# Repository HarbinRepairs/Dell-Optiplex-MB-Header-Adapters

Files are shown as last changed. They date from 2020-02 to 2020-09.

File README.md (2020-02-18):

# Front Panel Header Adapters for Dell Optiplex Motherboards

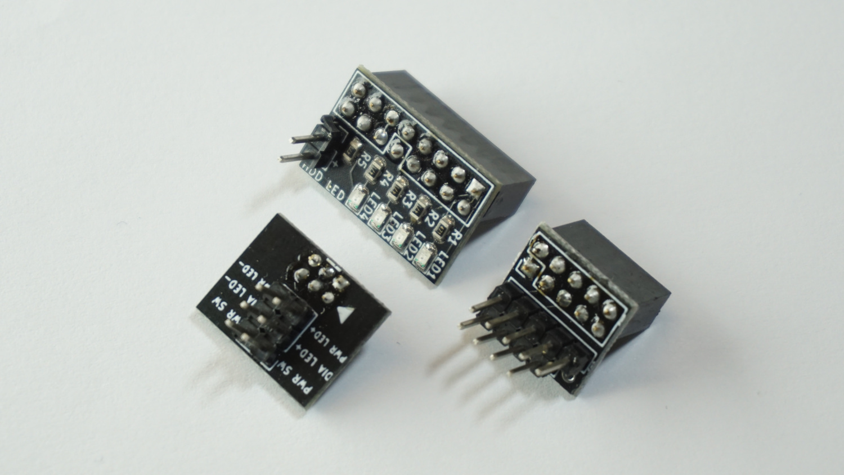
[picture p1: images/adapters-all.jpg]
Adapters


Get it at our store:

https://store.harbinrepairs.com/index.php/product/dell-optiplex-390-3010-3020-front-panel-header-adapter-3pc-kit/

https://store.harbinrepairs.com/index.php/product/dell-5-6-pin-power-button-led-panel-adapter/

Get it on eBay:

https://www.ebay.com/itm/264638815586

https://www.ebay.com/itm/264638806788

## License
Harbin Repairs 2020
Creative Commons Attribution ShareAlike 4.0
https://creativecommons.org/licenses/by-sa/4.0/

GNU General Public License v3.0

Harbin Repairs is not affiliated with Dell in any way shape or form.

## Documentation

This kit is designed for the mid tower (not SFF or small form factor) desktops. It allows you to connect standard PC case front panel headers to the Dell Optiplex 390, 3010, and 3020 motherboards. These are often used to build budget gaming PC’s using decommissioned office desktops and convert them to work with modern PC cases. WARNING! Connecting these adapters in the wrong orientation or with the wrong models could result in damage to your motherboard. Do not use these adapters with models other than the ones mentioned above and make sure to check out our assembly video below.

### Installation Guide Video

https://www.youtube.com/watch?v=3fb6-B5Ux_s

(https://www.youtube.com/watch?v=3fb6-B5Ux_s)

### Compatibility

The three piece adapter kit is only compatibile with the Dell optiplex 390, 3010, and 3020 DT & MT Dekstops. It will not work on the SFF desktops since they use a different connector and are not ideal since they do not have a removable I/O shield. The 5/6 pin power button however may work with most dell desktops that have a 5/6 pin header for the front panel power button/LED.

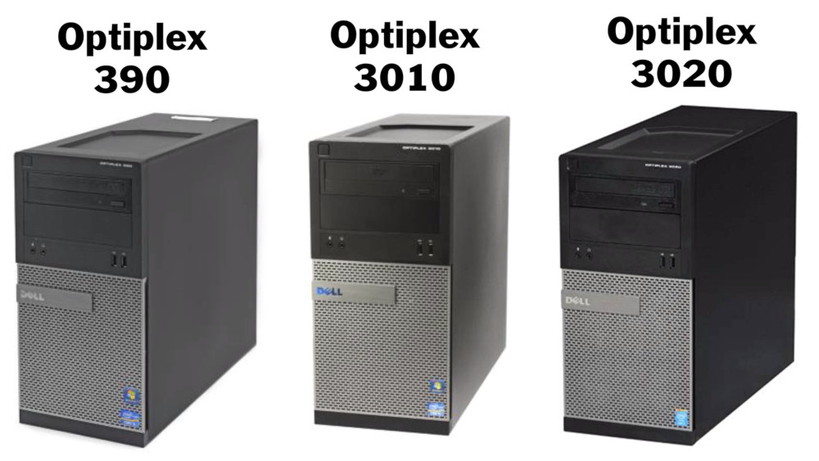
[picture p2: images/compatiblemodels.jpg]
Tower Comparison


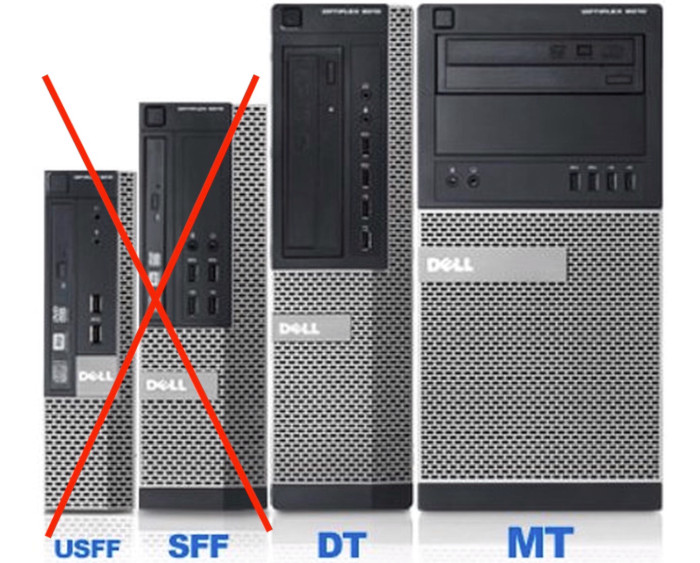
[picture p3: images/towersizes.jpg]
Tower Sizes


### Bill of Materials

| Qty | Description | Aliexpress | eBay Links (Affiliate)  | Amazon Links (Affiliate) |
|-----|---|---|---|---|
| 3 | PCB | Manufacturer of choice | | |
| 1 | 2x3 2mm 6pin Female Straight THT Connector | http://bit.ly/2SQY12E  | https://ebay.to/2P2j5lk | N/A |
| 1 | 2x5 2.54mm 10pin Female Straight THT Connector | http://bit.ly/3bOo6ru  | https://ebay.to/2ubbdXK | https://amzn.to/2u3uMky  |
| 1 | 2x8 2.54mm 16pin Female Straight THT Connector | http://bit.ly/39JsCpE  | https://ebay.to/2SA2zeA | https://amzn.to/2Hwy3Mr  |
| 1 | 1x40 2.54mm Male Pin Header THT | http://bit.ly/2HzO3NS  | https://ebay.to/2V6OmYa | https://amzn.to/38CYH2a  |
| 4 | 0805 SMD Yellow LED | http://bit.ly/38DWLGB  | https://ebay.to/2UW0tHL | https://amzn.to/38CjiUj  |
| 5 | 0805 SMD 470Ω Resistor | http://bit.ly/2SOXqOO  | https://ebay.to/38CF7D5 | https://amzn.to/38E2ThY  |

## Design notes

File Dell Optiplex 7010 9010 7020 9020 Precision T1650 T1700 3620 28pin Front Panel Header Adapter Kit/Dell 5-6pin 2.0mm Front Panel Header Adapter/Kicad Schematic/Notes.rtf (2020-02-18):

https://linustechtips.com/main/topic/925354-optiplex-7010-power-pinout/
https://linustechtips.com/main/topic/987783-optiplex-70109010-front-io-panel-pinout/

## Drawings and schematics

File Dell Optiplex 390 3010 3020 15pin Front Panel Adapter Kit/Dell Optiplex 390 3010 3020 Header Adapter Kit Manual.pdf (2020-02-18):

# Dell Optiplex Header Adapter Kit

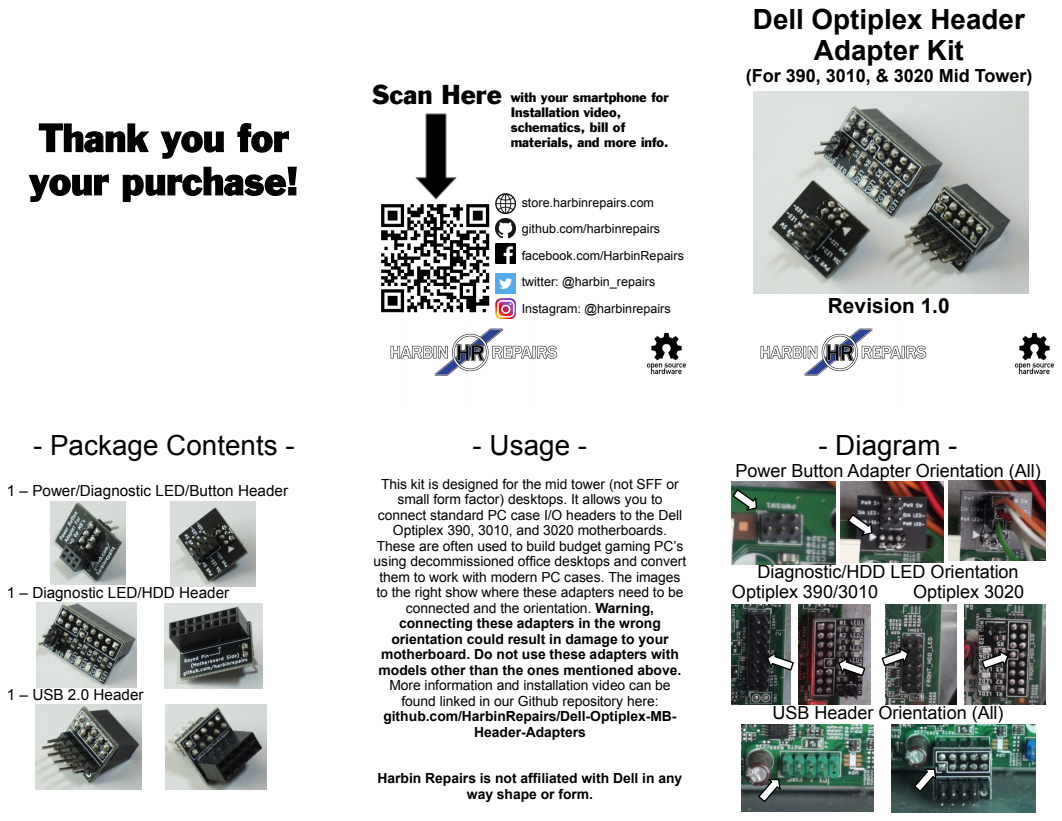
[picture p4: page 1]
Revision 1.0; Scan Here; twitter: @harbin_repairs; Instagram: @harbinrepairs; - Diagram -; Optiplex 390/3010; Optiplex 3020; - Usage -; Header-Adapters; - Package Contents -; 1 – USB 2.0 Header

(For 390, 3010, & 3020 Mid Tower)

with your smartphone for
Installation video,
schematics, bill of
materials, and more info.

Thank you for
your purchase!

store.harbinrepairs.com

github.com/harbinrepairs

facebook.com/HarbinRepairs

Power Button Adapter Orientation (All)

1 – Power/Diagnostic LED/Button Header

This kit is designed for the mid tower (not SFF or
small form factor) desktops. It allows you to
connect standard PC case I/O headers to the Dell
Optiplex 390, 3010, and 3020 motherboards.
These are often used to build budget gaming PC’s
using decommissioned office desktops and convert
them to work with modern PC cases. The images
to the right show where these adapters need to be
connected and the orientation. Warning,
connecting these adapters in the wrong
orientation could result in damage to your
motherboard. Do not use these adapters with
models other than the ones mentioned above.
More information and installation video can be
found linked in our Github repository here:
github.com/HarbinRepairs/Dell-Optiplex-MB-

Diagnostic/HDD LED Orientation

1 – Diagnostic LED/HDD Header

USB Header Orientation (All)

Harbin Repairs is not affiliated with Dell in any

way shape or form.

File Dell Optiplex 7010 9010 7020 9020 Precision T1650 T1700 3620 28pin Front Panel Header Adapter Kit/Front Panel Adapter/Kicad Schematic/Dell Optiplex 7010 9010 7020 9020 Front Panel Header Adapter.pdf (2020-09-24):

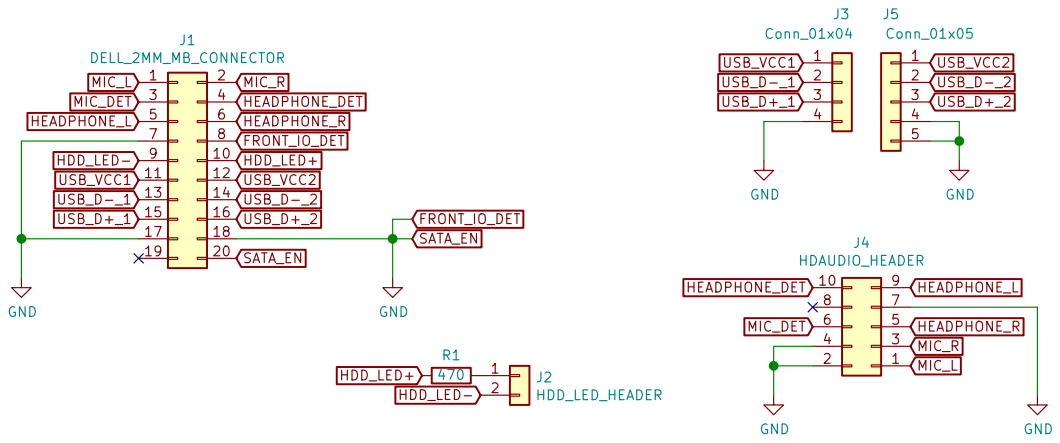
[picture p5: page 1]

File: Dell Optiplex 7010 9010 7020 9020 Front Panel Header Adapter.sch Sheet: / Harbin Repairs

Id: 1/1 Title: Front Panel Adapter For Dell Optiplex 7010 7020 9010 9020

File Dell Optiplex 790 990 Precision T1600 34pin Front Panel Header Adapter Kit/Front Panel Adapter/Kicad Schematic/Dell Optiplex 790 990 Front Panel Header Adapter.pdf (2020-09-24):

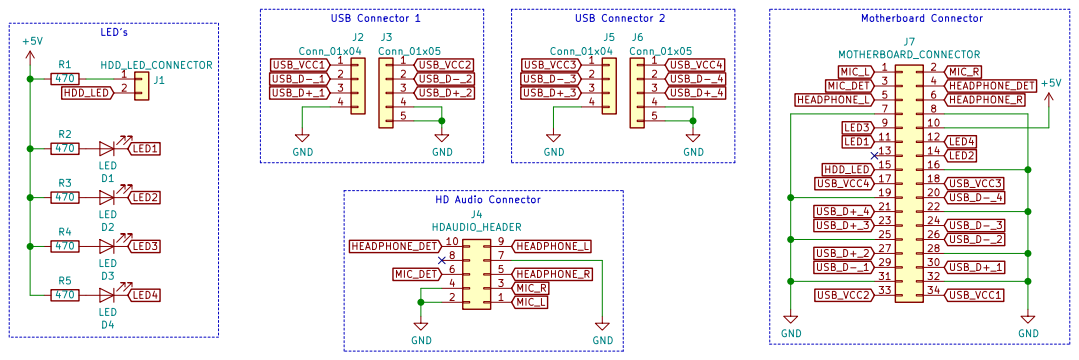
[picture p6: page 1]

File: Dell Optiplex 790 990 Front Panel Header Adapter.sch Sheet: / Harbin Repairs

Id: 1/1 Title: Front Panel Header Adapter For Dell Optiplex 790 & 990

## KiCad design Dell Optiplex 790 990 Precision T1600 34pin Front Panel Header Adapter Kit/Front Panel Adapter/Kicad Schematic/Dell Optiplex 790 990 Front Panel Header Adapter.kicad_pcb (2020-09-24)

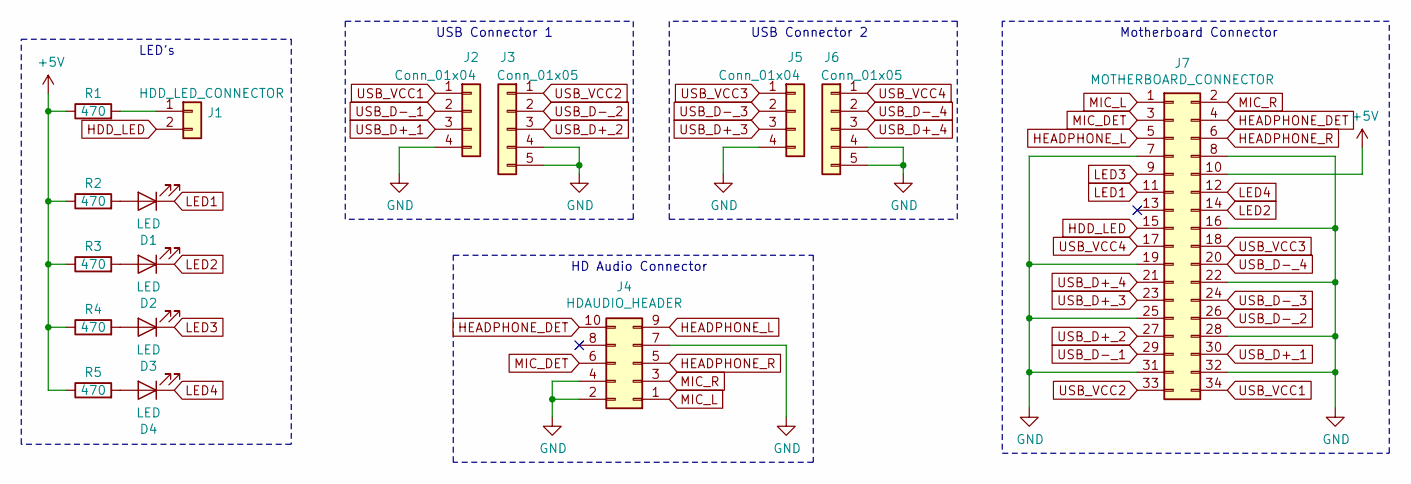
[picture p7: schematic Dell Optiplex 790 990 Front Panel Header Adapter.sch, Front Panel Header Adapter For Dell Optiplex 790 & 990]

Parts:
D1, D2, D3, D4: LED; LED_0805_2012Metric
J1: HDD_LED_CONNECTOR; PinHeader_1x02_P2.54mm_Vertical
J2, J5: Conn_01x04; PinHeader_1x04_P2.54mm_Vertical
J3, J6: Conn_01x05; PinHeader_1x05_P2.54mm_Vertical
J4: HDAUDIO_HEADER; PinHeader_2x05_P2.54mm_Vertical
J7: MOTHERBOARD_CONNECTOR; PinSocket_2x17_P2.00mm_Vertical
R1, R2, R3, R4, R5: 470; R_0805_2012Metric

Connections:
+5V: J7.10, R1.1, R2.1, R3.1, R4.1, R5.1
GND: J2.4, J3.4, J3.5, J4.2, J4.4, J4.7, J5.4, J6.4, J6.5, J7.7, J7.8, J7.16, J7.19, J7.22, J7.25, J7.28, J7.31, J7.32
HDD_LED: J1.2, J7.15
HEADPHONE_DET: J4.10, J7.4
HEADPHONE_L: J4.9, J7.5
HEADPHONE_R: J4.5, J7.6
LED1: D1.1 (K), J7.11
LED2: D2.1 (K), J7.14
LED3: D3.1 (K), J7.9
LED4: D4.1 (K), J7.12
MIC_DET: J4.6, J7.3
MIC_L: J4.1, J7.1
MIC_R: J4.3, J7.2
unnamed: D1.2 (A), R2.2
unnamed: D2.2 (A), R3.2
unnamed: D3.2 (A), R4.2
unnamed: D4.2 (A), R5.2
unnamed: J1.1, R1.2
USB_D+_1: J2.3, J7.30
USB_D+_2: J3.3, J7.27
USB_D+_3: J5.3, J7.23
USB_D+_4: J6.3, J7.21
USB_D-_1: J2.2, J7.29
USB_D-_2: J3.2, J7.26
USB_D-_3: J5.2, J7.24
USB_D-_4: J6.2, J7.20
USB_VCC1: J2.1, J7.34
USB_VCC2: J3.1, J7.33
USB_VCC3: J5.1, J7.18
USB_VCC4: J6.1, J7.17

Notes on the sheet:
USB Connector 1
USB Connector 2
HD Audio Connector
LED’s
Motherboard Connector

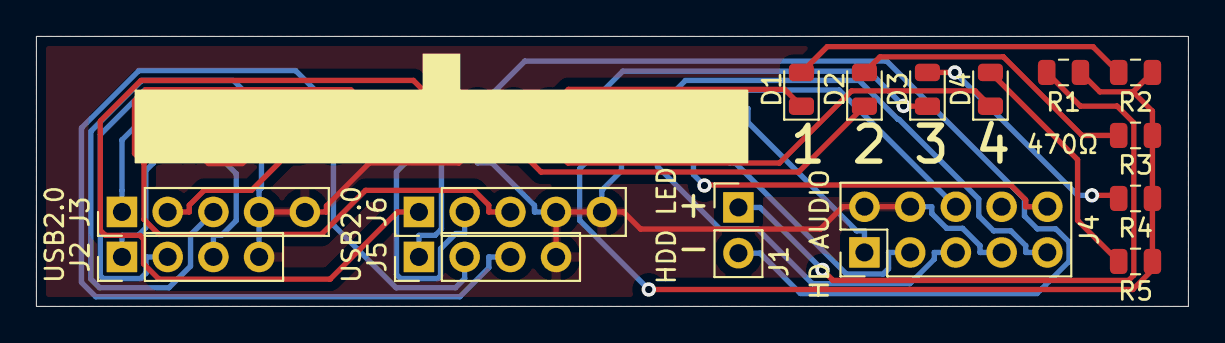
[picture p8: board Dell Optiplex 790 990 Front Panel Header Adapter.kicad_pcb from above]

Board: 2 copper layers, 64.0 x 15.0 mm, 16 parts (1 on the bottom side), 30 nets.

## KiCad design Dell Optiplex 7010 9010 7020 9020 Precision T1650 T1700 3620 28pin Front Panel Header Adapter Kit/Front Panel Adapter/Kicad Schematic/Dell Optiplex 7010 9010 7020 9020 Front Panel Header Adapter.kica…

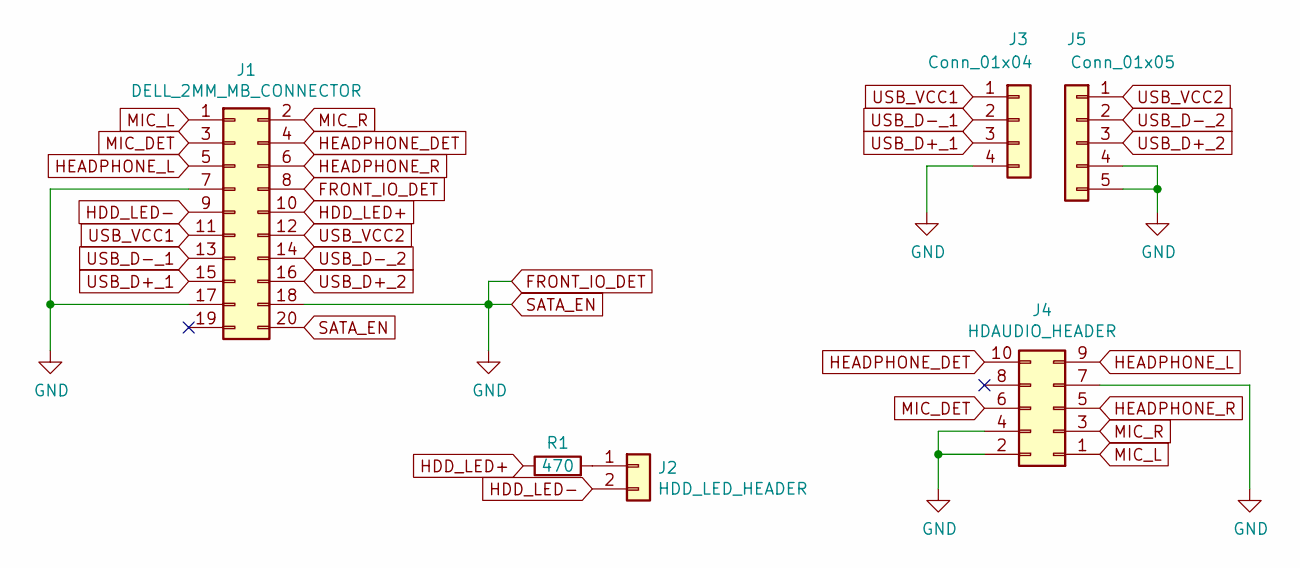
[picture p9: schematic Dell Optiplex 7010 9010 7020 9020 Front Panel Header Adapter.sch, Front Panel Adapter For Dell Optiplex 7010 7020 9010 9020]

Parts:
J1: DELL_2MM_MB_CONNECTOR; PinSocket_2x10_P2.00mm_Vertical
J2: HDD_LED_HEADER; PinHeader_1x02_P2.54mm_Vertical
J3: Conn_01x04; PinHeader_1x04_P2.54mm_Vertical
J4: HDAUDIO_HEADER; PinHeader_2x05_P2.54mm_Vertical
J5: Conn_01x05; PinHeader_1x05_P2.54mm_Vertical
R1: 470; R_0805_2012Metric

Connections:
FRONT_IO_DET: J1.7, J1.8, J1.17, J1.18, J1.20, J3.4, J4.2, J4.4, J4.7, J5.4, J5.5
HDD_LED+: J1.10, R1.1
HDD_LED-: J1.9, J2.2
HEADPHONE_DET: J1.4, J4.10
HEADPHONE_L: J1.5, J4.9
HEADPHONE_R: J1.6, J4.5
MIC_DET: J1.3, J4.6
MIC_L: J1.1, J4.1
MIC_R: J1.2, J4.3
unnamed: J2.1, R1.2
USB_D+_1: J1.15, J3.3
USB_D+_2: J1.16, J5.3
USB_D-_1: J1.13, J3.2
USB_D-_2: J1.14, J5.2
USB_VCC1: J1.11, J3.1
USB_VCC2: J1.12, J5.1

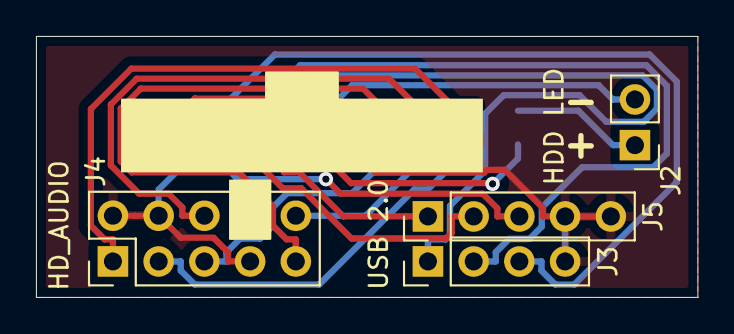
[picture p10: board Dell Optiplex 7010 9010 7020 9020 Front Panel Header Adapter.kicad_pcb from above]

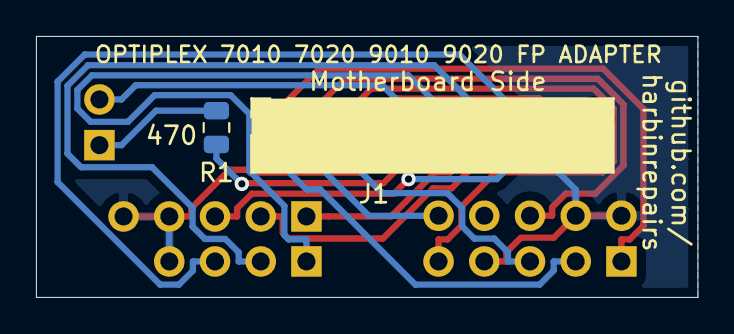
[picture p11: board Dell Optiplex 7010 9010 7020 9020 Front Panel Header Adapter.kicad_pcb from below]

Board: 2 copper layers, 36.8 x 14.5 mm, 6 parts (2 on the bottom side), 16 nets.

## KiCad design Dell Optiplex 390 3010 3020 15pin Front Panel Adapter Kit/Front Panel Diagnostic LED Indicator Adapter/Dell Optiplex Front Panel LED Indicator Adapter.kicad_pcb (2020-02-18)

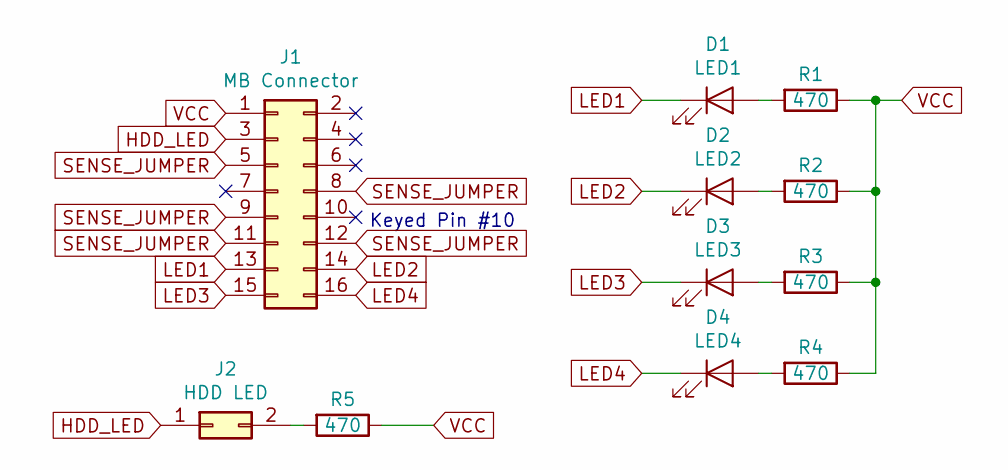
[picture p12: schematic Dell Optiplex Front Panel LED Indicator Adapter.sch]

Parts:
D1: LED1; LED_0805_2012Metric
D2: LED2; LED_0805_2012Metric
D3: LED3; LED_0805_2012Metric
D4: LED4; LED_0805_2012Metric
J1: MB Connector; PinSocket_2x08_P2.54mm_Vertical
J2: HDD LED; PinHeader_2x01_P2.54mm_Vertical
R1, R2, R3, R4, R5: 470; R_0805_2012Metric

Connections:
HDD_LED: J1.3, J2.1
LED1: D1.1 (K), J1.13
LED2: D2.1 (K), J1.14
LED3: D3.1 (K), J1.15
LED4: D4.1 (K), J1.16
unnamed: D1.2 (A), R1.2
unnamed: D2.2 (A), R2.2
unnamed: D3.2 (A), R3.2
unnamed: D4.2 (A), R4.2
unnamed: J2.2, R5.2
SENSE_JUMPER: J1.5, J1.8, J1.9, J1.11, J1.12
VCC: J1.1, R1.1, R2.1, R3.1, R4.1, R5.1

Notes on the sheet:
Keyed Pin #10

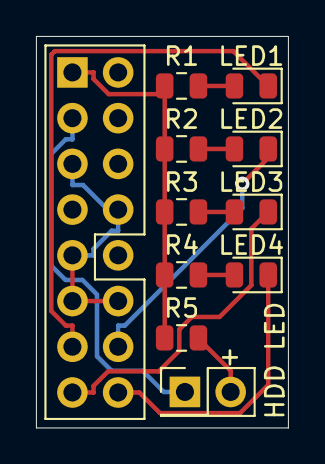
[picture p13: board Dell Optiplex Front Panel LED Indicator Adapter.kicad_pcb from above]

Board: 2 copper layers, 14.0 x 21.8 mm, 11 parts (1 on the bottom side), 12 nets.

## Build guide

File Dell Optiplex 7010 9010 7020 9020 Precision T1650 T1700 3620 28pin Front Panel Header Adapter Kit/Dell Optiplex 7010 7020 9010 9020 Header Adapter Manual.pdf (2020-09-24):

# Dell Optiplex/Precision Header Adapter Kit

## (Optiplex 7010, 7020, 9010, 9020 and Precision T1650, T1700, & 3620)

# Thank you for your purchase!

# Scan Here

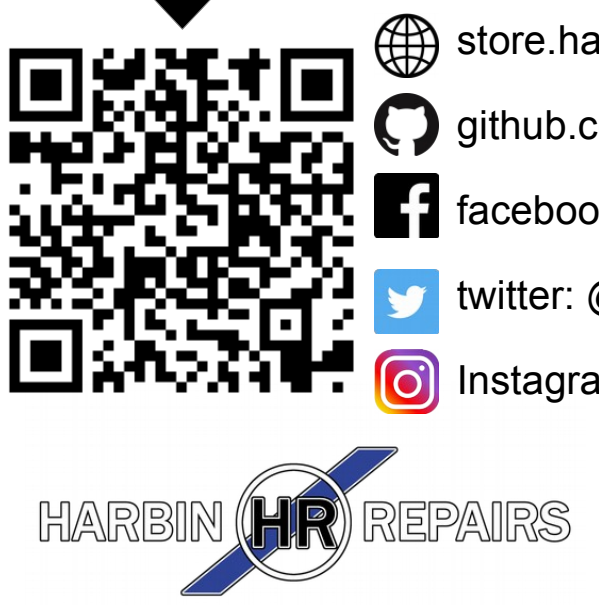
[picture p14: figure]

store.harbinrepairs.com

github.com/harbinrepairs

facebook.com/HarbinRepairs

twitter: @harbin_repairs

Instagram: @harbinrepairs

with your smartphone for
Installation video,
schematics, bill of
materials, and more info.

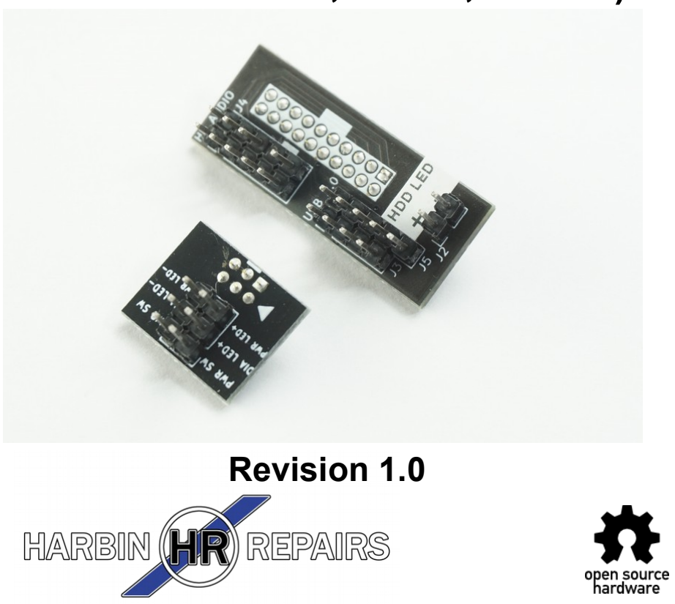
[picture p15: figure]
Revision 1.0

# Dell Optiplex/Precision Header Adapter Kit

## (Optiplex 7010, 7020, 9010, 9020 and Precision T1650, T1700, & 3620)

# Thank you for your purchase!

# Scan Here

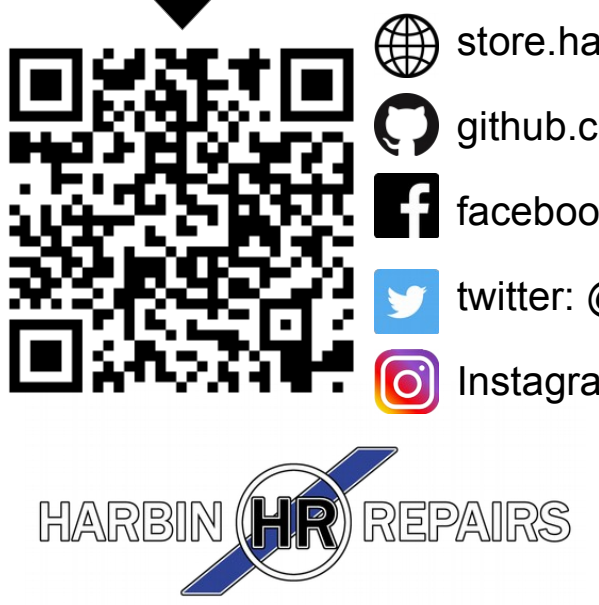
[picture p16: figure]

store.harbinrepairs.com

github.com/harbinrepairs

facebook.com/HarbinRepairs

twitter: @harbin_repairs

Instagram: @harbinrepairs

with your smartphone for
Installation video,
schematics, bill of
materials, and more info.

# - Diagram -

Power LED/Button Adapter Orientation

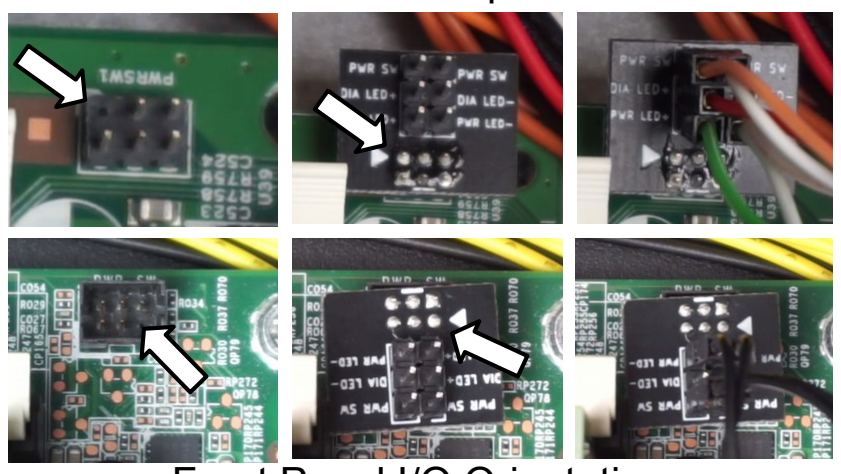
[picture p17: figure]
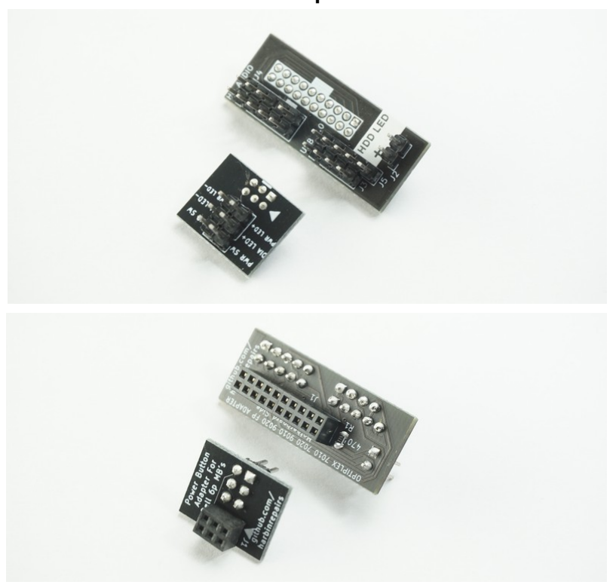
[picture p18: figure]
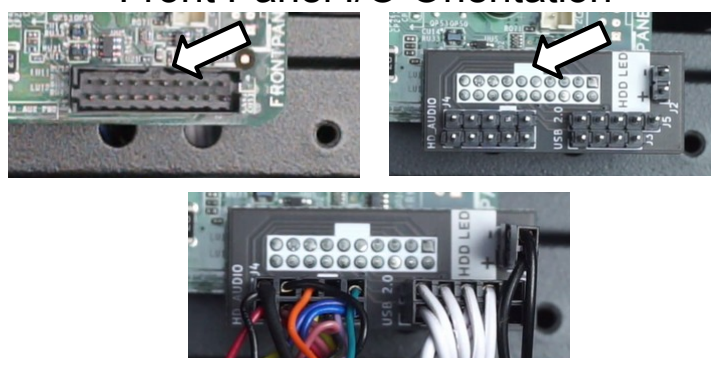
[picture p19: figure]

Front Panel I/O Orientation

# - Usage -

This kit is designed for the DT & MT mid tower (not SFF or small form factor) desktops. It allows you to connect standard PC case I/O headers to the Dell Optiplex 7010, 9010, 7020, 9020 and Precision T1650, T1700, & 3620 motherboards. These are often used to build budget gaming PC’s using decommissioned office desktops and convert them to work with modern PC cases. The images to the right show where these adapters need to be connected and the orientation. Warning, connecting these adapters in the wrong orientation could result in damage to your motherboard. Do not use these adapters with models other than the ones mentioned above. More information and installation video can be found linked in our Github repository here: github.com/HarbinRepairs/ Dell-Optiplex-MB-Header-Adapters

Harbin Repairs is not affiliated with Dell in any way shape or form.

# - Package Contents -

### 1 – Power LED/Button Adapter 1 – Front Panel I/O Adapter

# - Diagram -

Power LED/Button Adapter Orientation

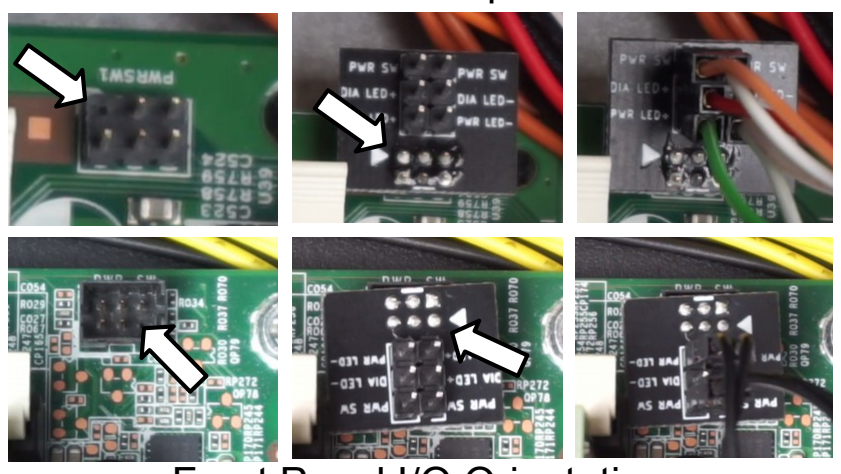
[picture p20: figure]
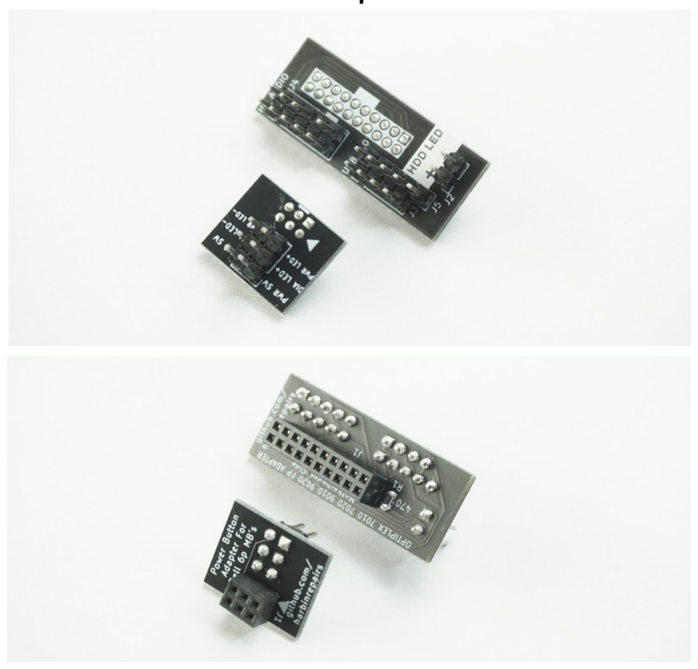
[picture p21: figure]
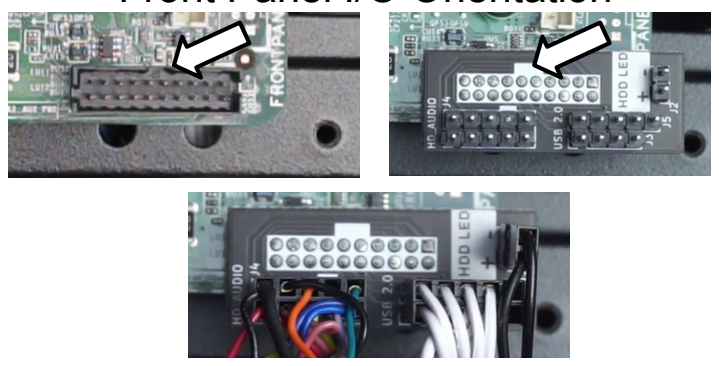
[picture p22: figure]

Front Panel I/O Orientation

# - Usage -

This kit is designed for the DT & MT mid tower (not SFF or small form factor) desktops. It allows you to connect standard PC case I/O headers to the Dell Optiplex 7010, 9010, 7020, 9020 and Precision T1650, T1700, & 3620 motherboards. These are often used to build budget gaming PC’s using decommissioned office desktops and convert them to work with modern PC cases. The images to the right show where these adapters need to be connected and the orientation. Warning, connecting these adapters in the wrong orientation could result in damage to your motherboard. Do not use these adapters with models other than the ones mentioned above. More information and installation video can be found linked in our Github repository here: github.com/HarbinRepairs/ Dell-Optiplex-MB-Header-Adapters

Harbin Repairs is not affiliated with Dell in any way shape or form.

# - Package Contents -

### 1 – Power LED/Button Adapter 1 – Front Panel I/O Adapter

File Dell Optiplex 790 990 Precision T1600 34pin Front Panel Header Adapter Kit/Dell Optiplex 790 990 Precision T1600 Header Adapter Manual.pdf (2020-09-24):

# Dell Optiplex/Precision Header Adapter Kit

## (Optiplex 790/990 & Precision T1600)

# Thank you for your purchase!

# Scan Here


store.harbinrepairs.com

github.com/harbinrepairs

facebook.com/HarbinRepairs

twitter: @harbin_repairs

Instagram: @harbinrepairs

with your smartphone for
Installation video,
schematics, bill of
materials, and more info.

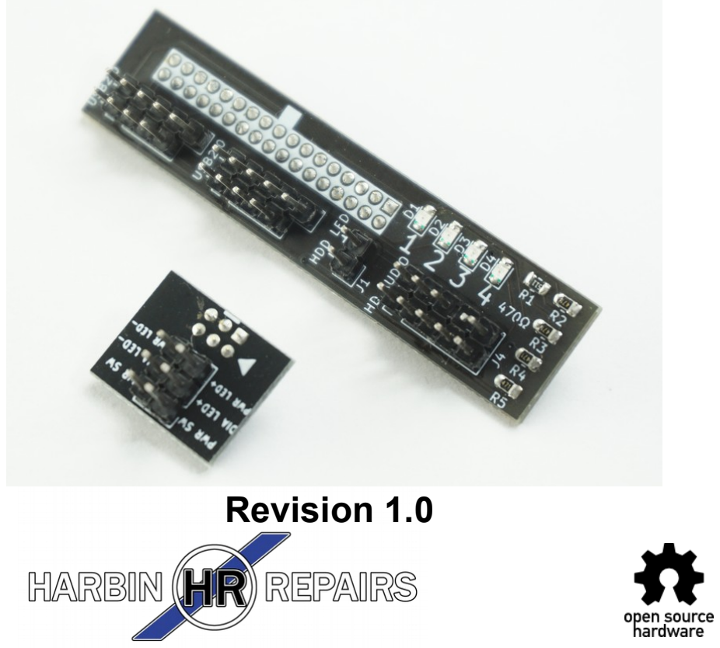
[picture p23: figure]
Revision 1.0

# - Diagram -

## Power LED/Button Adapter Orientation

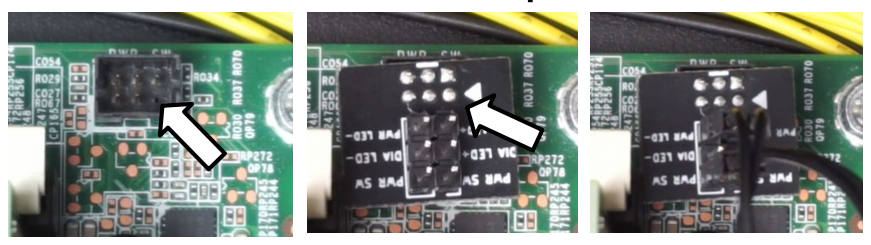
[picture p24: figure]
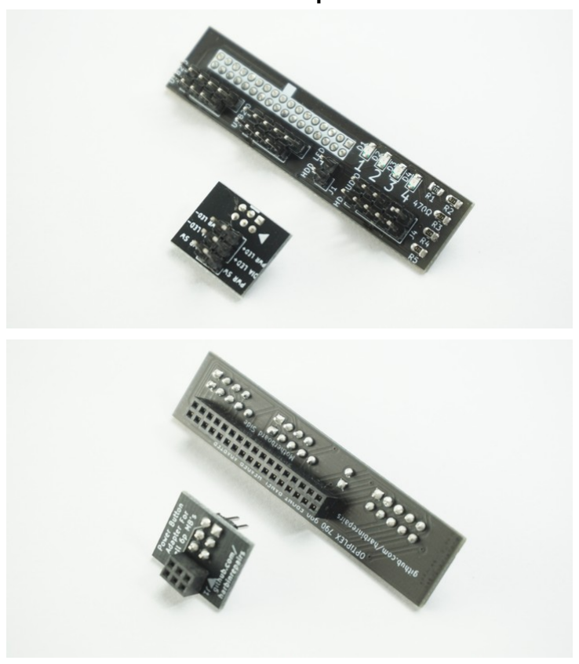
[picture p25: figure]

## Front Panel I/O Adapter Orientation

# - Usage -

This kit is designed for the DT & MT mid tower (not SFF or small form factor) desktops. It allows you to connect standard PC case I/O headers to the Dell Optiplex 790/990 & Precision T1600 motherboards. These are often used to build budget gaming PC’s using decommissioned office desktops and convert them to work with modern PC cases. The images to the right show where these adapters need to be connected and the orientation. The numbered LED’s correspond to the numbered LED’s that were originally on the front of the case to indicate error codes. Warning, connecting these adapters in the wrong orientation could result in damage to your motherboard. Do not use these adapters with models other than the ones mentioned above. More information and installation video can be found linked in our Github repository here: github.com/HarbinRepairs/Dell-Optiplex-MB-Header-Adapters

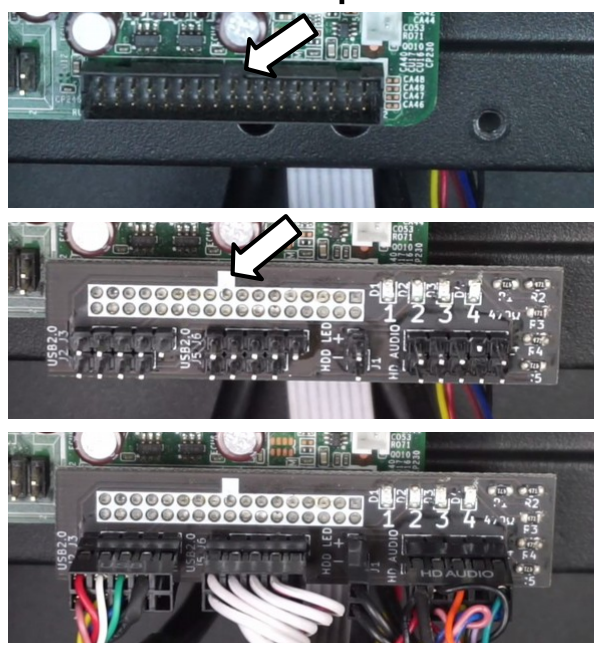
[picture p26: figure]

Harbin Repairs is not affiliated with Dell in any way shape or form.

# - Package Contents -

### 1 – Power LED/Button Adapter 1 – Front Panel I/O Adapter

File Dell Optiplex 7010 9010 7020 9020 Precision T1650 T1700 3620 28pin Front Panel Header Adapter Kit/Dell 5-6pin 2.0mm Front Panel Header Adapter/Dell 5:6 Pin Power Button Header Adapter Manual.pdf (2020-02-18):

# 5/6 Pin Power Button/LED Adapter

## (For Dell Desktop Motherboards)

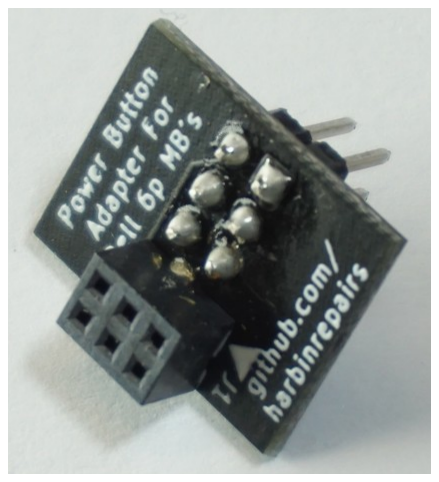
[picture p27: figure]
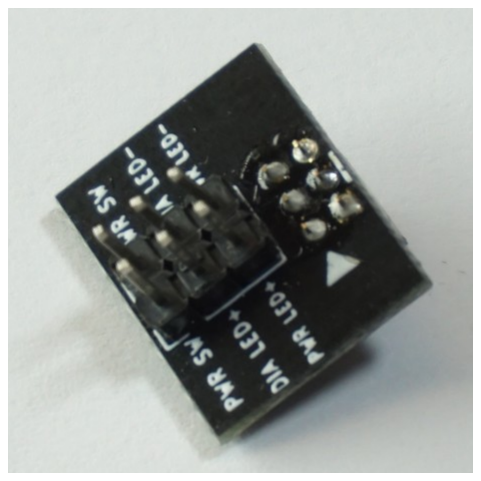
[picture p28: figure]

## Revision 1.0

# Thank you for your purchase!

# Scan Here


store.harbinrepairs.com

github.com/harbinrepairs

facebook.com/HarbinRepairs

twitter: @harbin_repairs

Instagram: @harbinrepairs

with your smartphone for
Installation video,
schematics, bill of
materials, and more info.

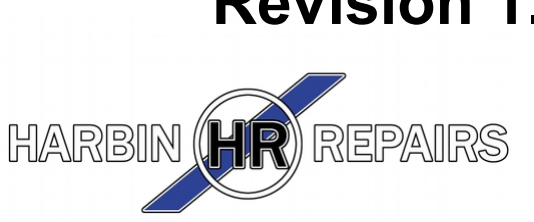
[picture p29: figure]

# - Diagram -

## Power Button Adapter Orientation

# - Usage -

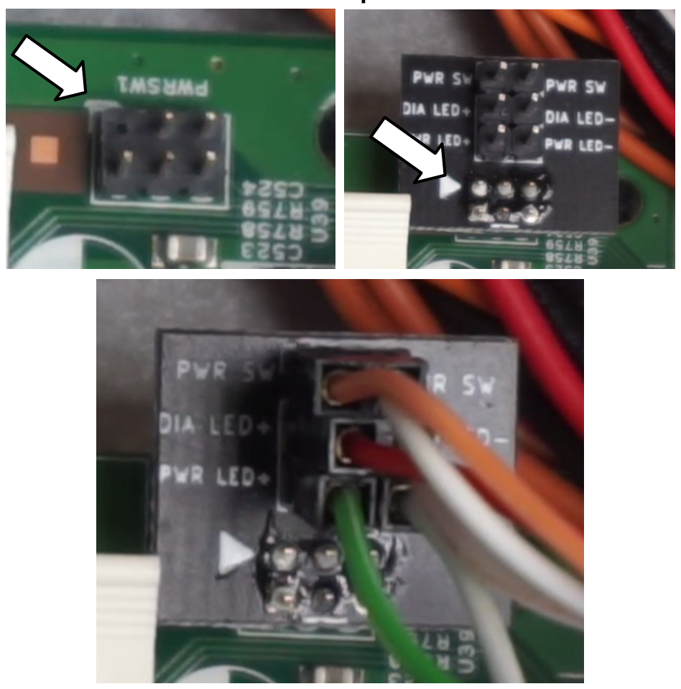
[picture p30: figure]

This adapter is designed to work with most Dell desktop motherboards that have a 5/6 pin header used to connect the power button, power LED, and diagnostic LED. This adapterallows you to use connect the front panel power button and power LED on a modern PC case to the proprietary connector used on most Dell desktops. These are commonly used to build budget gaming PC’s using decommissioned office desktops and convert them to work with modern PC cases. Make sure to connect the LED connectors to the adapter matching the correct polarity. The images to the right show where these adapters need to be connected and the orientation. Warning, connecting these adapters in the wrong orientation could result in damage to your motherboard. More information and installation video can be found linked in our Github repository here: github.com/HarbinRepairs/Dell-Optiplex-MB-Header-Adapters

Harbin Repairs is not affiliated with Dell in any way shape or form.

# - Package Contents -

### 1 – Power/Diagnostic LED/Button Header

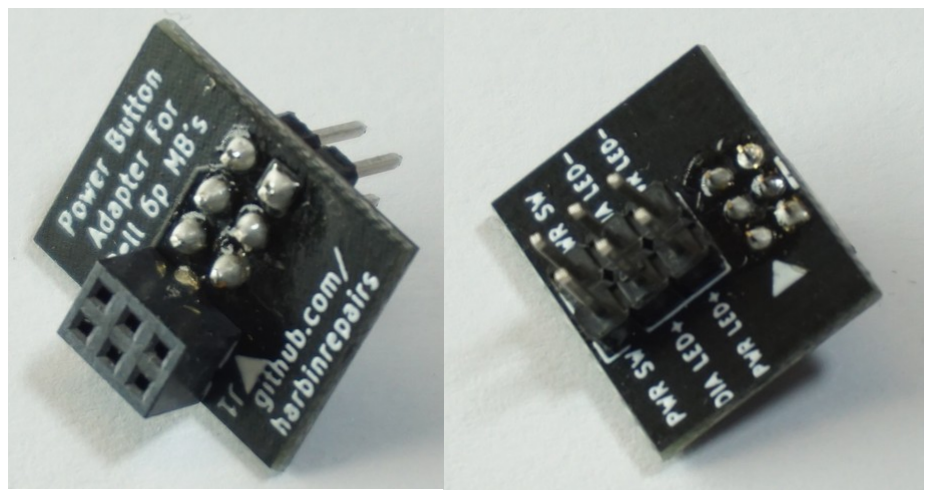
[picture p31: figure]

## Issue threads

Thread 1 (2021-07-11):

why not 9020 sff?

asheenlevrai, 2021-07-11:
Hi :)

Why won't the front panel adapter kit work with 9020 sff (and usff)?

Is there any chance you will make an adapter that is compatible with the 9020 sff?

Thank you very much in advance.
Best,
-a-

HarbinRepairs, 2021-08-09:
The current motherboard adapter (DFP19-T) will not work with SFF due to the connector being in a different area that is constrained and/or it might have a different connector than the MT variant. We plan to make adapters for the SFF models in the future.

Closed 2021-08-09.

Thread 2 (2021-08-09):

Dell power adapter

Capnklayton, 2021-08-09:
I’m using the power adapter for optiplex 990 and running into the post power error at the beginning. I should work for 990 right it looks like the front panel adapter is working flawlessly.

HarbinRepairs, 2021-08-09:
If you are referring to the power button adapter (DFP05-PWR-T) then that adapter alone will not resolve the front panel I/O error, you also must have the DFP34-T adapter installed for the front panel I/O error to clear. If this is an SFF model then unfortunately we don't have an adapter for that model as of right now.

Capnklayton, 2021-08-09:
I figured it out. Turned the adapter opposite the white line where the arrow matches the missing pin.

Capnklayton, 2021-08-09:
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heres a photo

Closed 2021-08-09.

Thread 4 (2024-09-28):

Diagnostic/HDD LED. LEDs don't turn on

LostAccount, 2024-09-28:
Hello

I have an Optiplex 3020 Tower and using your adapters there is no issue. They work fine but why don't any of the LEDs work? Is the adapter limited when it comes to the 3020 Tower? Are the LEDs not expected to light up?

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

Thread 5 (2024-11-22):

Dell Optiplex 990/etc Adapter not compatible with some Dell Optiplex 990 motherboards

starhawk64, 2024-11-22:
My Dell Optiplex 990 board (purchased for a non-Dell build), DP/N 0D6H9T, has the 34pin connector in the rear I/O header area, just behind the dual audio ports, and to the side of a stack of two USB ports and a LAN jack. 34pin 2mm-pitch IDC ribbon cables are unobtanium, and the PCB as designed will not fit. I don't have the resources to either make or obtain custom PCBs of my own.

What do I do?

HarbinRepairs, 2024-11-24:
Unfortunately that board is the small form factor (SFF) version of the Optiplex 990 which has the connector in a different location making our DFP34-TK adapter kit incompatible (our adapter only works with the MT/DT variant). Currently we don't make an adapter for that model since there's not much demand due to it's age and we also cannot seem to find a ribbon extension cable for our adapter unless it's custom made to order from China. The only option is to splice the wires from the original front panel assembly to your new case front panel at this time.

starhawk64, 2024-11-25:
It would be easy enough to add support for this motherboard with a single bridge PCB and a pair of 34pin (2x17) 2mm-pitch pin headers. Probably the easiest design, from the user's perspective, would be to basically rest the bridge PCB atop the capacitors in between the CPU socket and the I/O Shield area at the back of the board, tucking the original breakout adapter partially under the heatsink behind the DP and PS/2 mouse/keyboard port pair. That would be a longish but simple sort of vaguely L-shaped PCB.

A second, potentially cheaper option, albeit one with much more complicated trace routing, would be to create a smaller, 'chunky' bridge PCB that puts the adapter 'under' the second PCI-E x16 slot, parallel with the slot.

Alternately, an option to bundle in one of those 34pin cables from China would be welcome as well, if a deal can be made.

I'm happy to assist with testing if you want to try for one of those. I'd really appreciate having an option here other than eating the money sunk into your adapter -- unfortunately I'm not qualified to design PCBs, and I'm on a deadline with one of these boards -- as I'm a young fellow on Disability, with limited resources, trying to help a local family of even more difficult circumstances as much as I can.

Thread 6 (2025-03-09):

Compatibility with 3010 sff

dinamitebla, 2025-03-09:
Hello, I was searching for a way to case swap my Dell 3010 and I came across this project. You mention that your adapters are not compatible with the SFF version of the 3010, but after reviewing the PCB schematics and probing some pins on my front panel connector, it seems they are perfectly identical. Am I missing something?
